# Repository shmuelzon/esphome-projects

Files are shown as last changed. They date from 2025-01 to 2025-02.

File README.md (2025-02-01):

# ESPHome Projects

This repository holds some of the ESPHome-based projects I've developed.

The directory structure is as follows:
* In the root you will find all of the ESPHome YAML files for each projects
* 3D-printable cases, if applicable, can be found in the [3d](./3d) directory
  * This were written for OpenSCAD but generated STL files are included
  * Note that each STL file may include multiple objects, e.g., the top and bottom part of a case. Make sure to separate those in your slicer before slicing and printing
* The [doc](./doc) directory holds the build information for each project

## List of Projects

| Image | Description | Documentation |
| ----- |:----:|:----:|
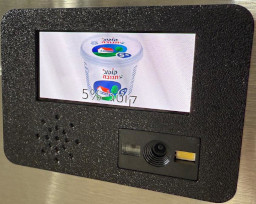
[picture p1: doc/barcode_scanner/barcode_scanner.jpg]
| [](./doc/barcode_scanner#readme) | Barcode Scanner that automatically add items to groceries list while displaying an image of the product and calling out it's name | [Documentation](./doc/barcode_scanner#readme) |
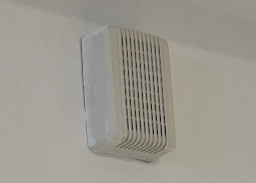
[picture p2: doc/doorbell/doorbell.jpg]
| [](./doc/doorbell#readme) | Doorbell with customizable audio tracks and media player for HA text-to-speech | [Documentation](./doc/doorbell#readme) |

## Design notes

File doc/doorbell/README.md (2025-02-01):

# Doorbell

This project is meant as a drop-in replacement to my existing doorbell buzzer. It uses the same infrastructure and illuminated push-button for activating it.

## Build

### Bill of Materials

| Name | Image | Quantity | Comments |
| ---- | ----- | --- | --- |
| SeeedStudio XIAO ESP32S3 |  XIAO ESP32S3 | 1 | |
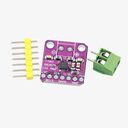
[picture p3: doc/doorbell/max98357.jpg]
MAX98357
| MAX98357 I2S Audio Amplifier Module |  | 1 | |
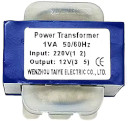
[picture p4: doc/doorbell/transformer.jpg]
Transformer
| Transformer |  | 1 | 220v -> 12v |
| AC-DC Power supply | Power supply | 1 | 5v |
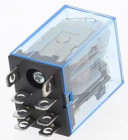
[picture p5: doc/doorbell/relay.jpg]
AC Relay
| AC Relay |  | 1 | 12v AC |
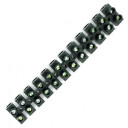
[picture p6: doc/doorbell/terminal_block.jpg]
| Terminal block |  | 4 | Split to two pairs |
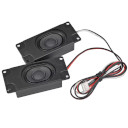
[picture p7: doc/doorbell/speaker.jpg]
Speaker
| Speaker |  | 1 | 4 Ohm, 3W |
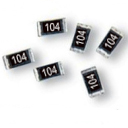
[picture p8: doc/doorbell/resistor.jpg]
100k resistor
| 100k resistor |  | 1 | Optional, set's the Amplifier to 15dB gain instead of 9dB |
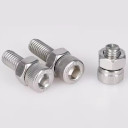
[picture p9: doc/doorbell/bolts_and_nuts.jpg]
M3x10 bolts and nuts
| M3x10 bolts and nuts |  | 4 | |

## Connections

MAX98357:
* LRC -> GPIO 44
* BCLK -> GPIO 7
* DIN -> GPIO 8
* Gain -> 100K resistor, the other end of the resistor to GND
* GND -> GND
* VIN -> 3.3v

Speaker:
* Red -> MAX98357 +
* Black -> MAX98357 -

Transformer:
* Primary (side with 2 pins) -> Live (AC) terminal block
* Secondary side -> One pin to the relay input and another to the button terminal block

Relay:
* Coil -> One side to the transformer, the other to the button terminal block
* Top contact (closer to the coil) -> GPIO 1
* Middle contact -> GND

AC-DC power supply:
* Mains -> Live (AC) terminal block
* 5v -> Xiao 5v
* GND -> GND

Live terminal block:
* AC Phase and neutral

Button terminal block:
* 2 leads to the illuminated doorbell push button

## Images
| Front | Back |
| ----- | ---- |
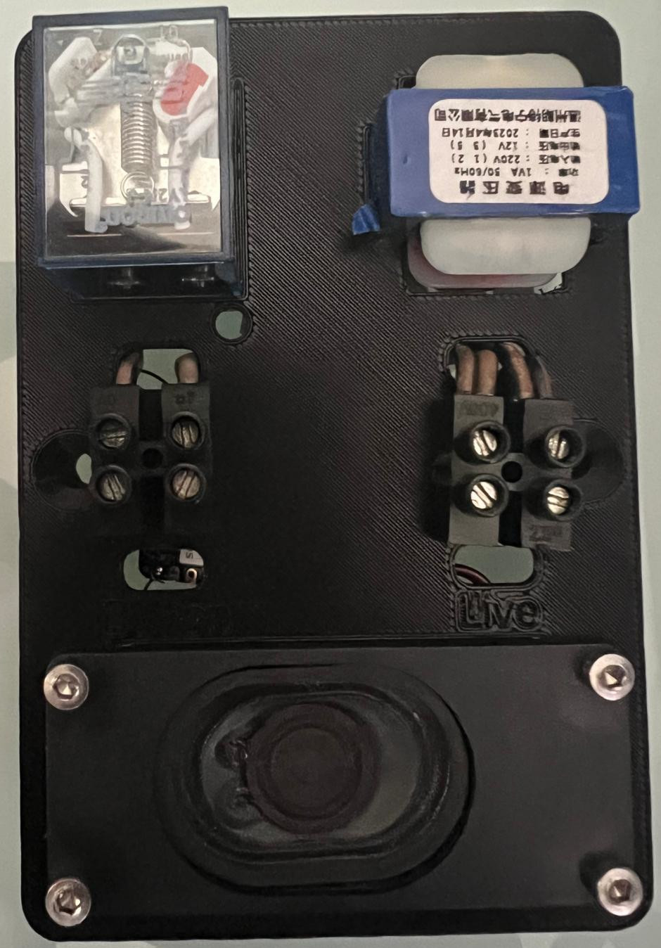
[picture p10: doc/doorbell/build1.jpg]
Build 1
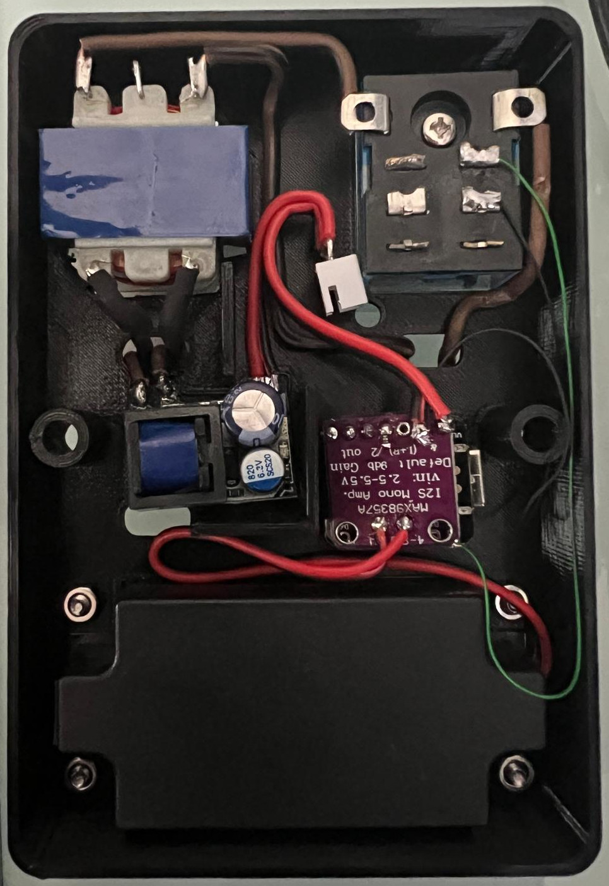
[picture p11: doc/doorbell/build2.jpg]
Build 2
|  |  |

## Misc

### Media Player

The doorbell also functions as a Home Assistant media player meaning you can play any supported audio on it, as well as use text-to-speech actions on it for various notifications.

### MQTT

While Home Assistant already enumerates the button for automations and such, I also opted to enable MQTT so that other services, e.g., Scrypted, can get events when the doorbell is pressed. The topic for the button is `doorbell/binary_sensor/button/state` with a payload of `ON` or `OFF`.

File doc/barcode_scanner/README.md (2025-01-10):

# Barcode Scanner

## Build

### Bill of Materials

| Name | Image | Quantity | Comments |
| ---- | ----- | --- | --- |
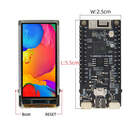
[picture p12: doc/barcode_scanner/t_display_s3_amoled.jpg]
S3 AMOLED
| LILYGO T-Display S3 AMOLED |  | 1 | v2.0, without touch screen nor soldered pins |
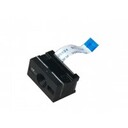
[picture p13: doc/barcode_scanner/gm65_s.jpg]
GM65-S
| GM65-S Barcode Scanner |  | 1 | |
| MAX98357 I2S Audio Amplifier Module | MAX98357 | 1 | |
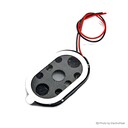
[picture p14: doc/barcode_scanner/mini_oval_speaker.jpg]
Speaker
| Mini Oval Speaker|  | 1 | 24x15mm 8ohm 1w |
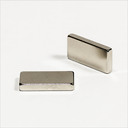
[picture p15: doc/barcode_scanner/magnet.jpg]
Magnet
| Magnet |  | 2 | Only needed for mounting on, for example, a refrigerator |
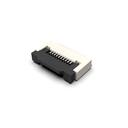
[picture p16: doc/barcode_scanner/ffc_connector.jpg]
FFC Connector
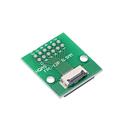
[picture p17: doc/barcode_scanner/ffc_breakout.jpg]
FFC Breakout
| FFC connector / breakout board |  /  | 1 | 12p 0.5mm pitch |
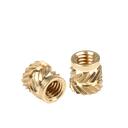
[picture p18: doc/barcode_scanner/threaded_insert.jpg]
Threaded inserts
| Threaded inserts |  | 3 | M3x5 |
| Countersunk screws | Countersunk screws | 3 | M3x8 |
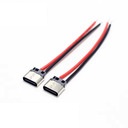
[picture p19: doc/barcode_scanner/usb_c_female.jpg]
USB-C Female
| USB-C Female |  | 1 | Should be as short as possible. I resoldered the leads to point the other way so it would sit flush in the case |
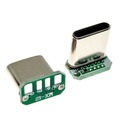
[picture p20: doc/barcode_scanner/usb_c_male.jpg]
USB-C Male
| USB-C Male |  | 1 | Should be as short as possible |
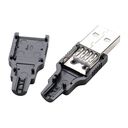
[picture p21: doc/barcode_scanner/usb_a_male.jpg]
USB-A Male
| USB-A Male |  | 1 | Depending on power source |

## Connections

Barcode Scanner:
* Pin 2 (VCC) -> 3.3v
* Pin 3 (GND) -> GND
* Pin 4 (RX) -> GPIO 43
* Pin 5 (TX) -> GPIO 44

> [!TIP]
> You might also need, even if temporarily, to connect pin 12 of the scanner to set it up. See the [Barcode Scanner Setup](#barcode-scanner-setup) section for more information

MAX98357:
* LRC -> GPIO 42
* BCLK -> GPIO 41
* DIN -> GPIO 40
* GND -> GND
* VIN -> 3.3v

USB-C Female:
* Red -> 5V
* Black -> GND

## Images
| Front | Back |
| ----- | ---- |
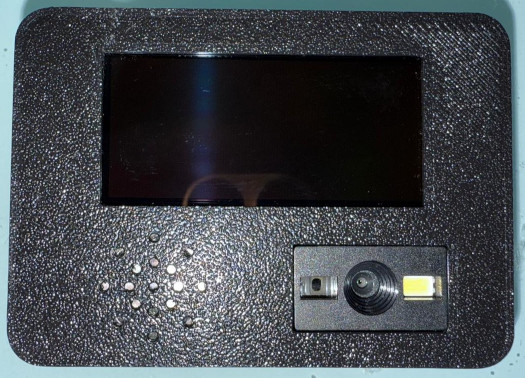
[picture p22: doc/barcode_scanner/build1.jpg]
Build 1
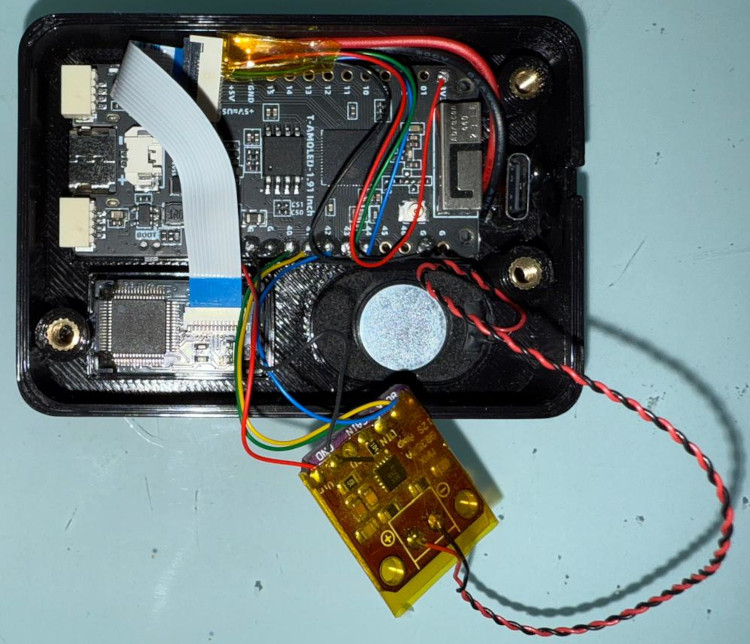
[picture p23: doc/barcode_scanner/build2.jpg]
Build 2
|  |  |

## Home Assistant

* Place font file (e.g., `DejaVuSans.ttf`) in `/config`
* Place the [barcode_unknown.png](./barcode_unknown.png) image in `/config/www`

### Configuration

We need to make use of the following Home Assistant integrations for retrieving the product information and for generating the display image with the product name overlaid:

> [!NOTE]
> Change the font name of the shell command to match the chosen font file

```yaml
rest_command:
  product_from_barcode:
    url: "https://world.openfoodfacts.org/api/v2/product/{{ barcode }}?fields=brands,product_name,product_name_he,code,selected_images"
    timeout: 30

shell_command:
  barcode_image: ffmpeg -i {{ image_url }} -vf "scale=536:240:force_original_aspect_ratio=decrease,pad=536:240:x=(536-iw)/2:y=(240-ih)/2:color=white,drawtext=text='{{ caption | replace("'", "'\\\\\\\\\\\''") }}':fontfile=/config/DejaVuSans.ttf:x=(w-text_w)/2:y=(h-text_h):fontsize=48:fontcolor=black:borderw=1:bordercolor=white:expansion=none" -frames:v 1 -update 1 -y {{ destination }}
```

### Automation

The following automation will trigger when a barcode is detected and attempt to retrieve its information. If it succeeds, it'll create an image to display and use TTS to send the product name to the scanner. Finally, it'll add the product to your to-do list. If the product isn't detect and "unknown" image will be displayed and a notification sent.

> [!NOTE]
> The below automation prioritizes the Hebrew product names and images, be sure to change that, if needed.
>
> Change the `<HA IP>` place holder with the IP address / host name of your Home Assistant Instance.
>
> Change the to-do list and notify actions to match your setup.

```yaml
alias: Add item to shopping list
description: ""
triggers:
  - trigger: state
    entity_id:
      - sensor.barcode_scanner_barcode
conditions:
  - condition: not
    conditions:
      - condition: state
        entity_id: sensor.barcode_scanner_barcode
        state: unknown
      - condition: state
        entity_id: sensor.barcode_scanner_barcode
        state: unavailable
actions:
  - variables:
      barcode: |
        {{ states('sensor.barcode_scanner_barcode') }}
  - action: rest_command.product_from_barcode
    data:
      barcode: "{{ barcode }}"
    response_variable: barcode_response
  - if:
      - condition: template
        value_template: >-
          {{ barcode_response['status'] == 200 and
          barcode_response['content']['product'].get('product_name','') != ''
          and barcode_response['content']['product'].get('selected_images') !=
          None }}
    then:
      - variables:
          product_name: >
            {{ barcode_response['content']['product']['product_name_he'] if
            barcode_response['content']['product'].get('product_name_he', '') !=
            '' else barcode_response['content']['product']['product_name'] }}
          product_brand: >
            {{ barcode_response['content']['product'].get('brands',
            '').split(',')[0] }}
          product_image: >
            {{
            barcode_response['content']['product']['selected_images']['front']['display']['he']
            if
            barcode_response['content']['product']['selected_images']['front']['display'].get('he')
            != None else
            barcode_response['content']['product']['selected_images']['front']['display']['en']
            }}
          product_full_name: |
            {{ product_name }} {{ product_brand }}
      - action: shell_command.barcode_image
        data:
          image_url: "{{ product_image }}"
          caption: "{{ product_name }}"
          destination: /config/www/barcode_product.png
      - action: text.set_value
        metadata: {}
        data:
          value: >-
            http://<HA IP>:8123/local/barcode_product.png?random={{
            as_timestamp(now()) | int }}
        target:
          entity_id: text.barcode_scanner_product_image_url
        enabled: true
      - action: tts.speak
        metadata: {}
        data:
          cache: true
          media_player_entity_id: media_player.barcode_scanner_media_player
          message: "{{ product_full_name }}"
          options:
            voice: he-IL-HilaNeural
        target:
          entity_id: tts.azure_ai_speech
      - if:
          - condition: template
            value_template: >-
              {{ product_full_name not in state_attr('todo.groceries_list',
              'all_todos') | map(attribute='subject') | list }}
        then:
          - action: todo.add_item
            metadata: {}
            data:
              item: "{{ product_full_name }}"
            target:
              entity_id: todo.groceries_list
          - action: notify.someone
            data:
              message: "{{ product_full_name }} was added to the groceries list"
    else:
      - action: text.set_value
        metadata: {}
        data:
          value: >-
            http://<HA IP>:8123/local/barcode_unknown.png?random={{
            as_timestamp(now()) | int }}
        target:
          entity_id: text.barcode_scanner_product_image_url
        enabled: true
      - action: notify.someone
        data:
          message: "Unknown barcode was scanned: {{ barcode }}"
mode: single
```

## Misc

### Barcode Scanner Setup

To simplify the project, I've opted to set the scanner to work in continuous mode without waiting between attempts. Look for the GM65-S manual online and you'll find QR codes you can scan to configure the device it self. Note that you'll need to trigger the scanner at least once to set it to continuous mode.  This is done by pulling pin 12 to low.

### Beep Sound

The common cash register sound is a 860 Hz square wave. I created a similar one (sine wave) with FFmpeg:

```shell
ffmpeg -f lavfi -i "sine=frequency=860:sample_rate=16000:duration=0.2" -ac 1 -af "volume=20dB" -sample_fmt s16 -c:a flac -y sounds/beep_of_a_cash_register.flac
```

### Open Food Facts Proxy

Sometimes Open Food Fact's website is a bit slow to respond. If you find that's the case often, you might want to consider adding a caching reverse-proxy. The following nginx configuration seems to work:

```nginx
http {
    proxy_cache_path  /cache levels=1:2 keys_zone=my-cache:8m max_size=1000m inactive=1y;
    proxy_temp_path /cache/tmp;

    server {
        listen 8081;
        listen [::]:8081;

        location / {
            proxy_pass https://world.openfoodfacts.org;
            proxy_cache my-cache;
            proxy_cache_valid 1y;
            proxy_cache_bypass $http_invalidate_cache;
        }
    }
}
```

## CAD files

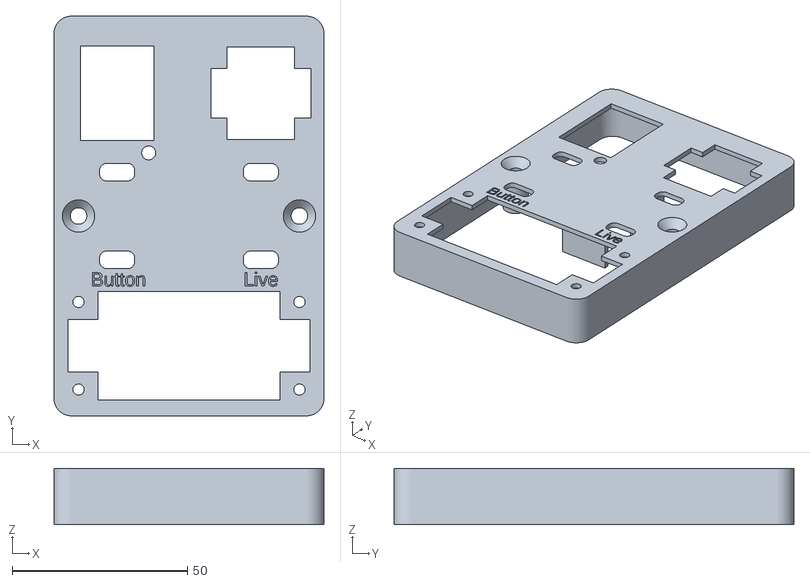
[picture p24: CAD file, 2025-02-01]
3d/doorbell.stl
77.0 x 114.0 x 16.0

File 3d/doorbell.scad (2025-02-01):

$fn=36;

/* General */
epsilon = 0.01;
mechanical_clearence = 0.1; /* Set according to printer's accuracy */

/* Case */
case_wall_thickness = 1.6;
case_depth = 16;
case_width = 77;
case_height = 114;
case_edge_radius = 5;

module round_cube(size=[0, 0, 0], r=2)
{
  minkowski()
  {
    cube([size[0] - (2 * r), size[1] - (2 * r), size[2] - 0.01]);
    translate([r, r, 0]) cylinder(r=r, h=0.01);
  }
}

module centered_cube(size=[0, 0, 0])
{
  translate([-size[0] / 2, -size[1] / 2, 0]) cube(size);
}

module countersunk_screw(length)
{
  color("gray")
  {
    cylinder(h=3, r1=4.5 + mechanical_clearence, r2=2.25 + mechanical_clearence);
    translate([0, 0, 3]) cylinder(h=length, r=2.25 + mechanical_clearence);
  }
}

module m3_hex_screw(length)
{
  color("gray")
  {
    cylinder(h=2, r=2.2 + mechanical_clearence);
    translate([0, 0, 2]) cylinder(h=length, r=1.5 + mechanical_clearence);
  }
}

module case()
{
  difference()
  {
    round_cube([case_width, case_height, case_depth], r=case_edge_radius);
    translate([case_wall_thickness, case_wall_thickness, -case_wall_thickness]) round_cube([case_width - (case_wall_thickness * 2), case_height - (case_wall_thickness * 2), case_depth], r=case_edge_radius);
    /* Button wiring */
    translate([13, 67, case_depth - case_wall_thickness - epsilon]) round_cube([10, 5, case_wall_thickness + (2 * epsilon)]);
    translate([13, 42, case_depth - case_wall_thickness - epsilon]) round_cube([10, 5, case_wall_thickness + (2 * epsilon)]);
    translate([10.5, 37, case_depth - 0.5]) linear_extrude(height=0.5) text("Button", size=4);
    /* Live wiring */
    translate([54, 67, case_depth - case_wall_thickness - epsilon]) round_cube([10, 5, case_wall_thickness + (2 * epsilon)]);
    translate([54, 42, case_depth - case_wall_thickness - epsilon]) round_cube([10, 5, case_wall_thickness + (2 * epsilon)]);
    translate([54, 37, case_depth - 0.5]) linear_extrude(height=0.5) text("Live", size=4);
    /* Antenna wire */
    translate([27, 75, case_depth - case_wall_thickness - epsilon]) cylinder(r = 2, h = case_wall_thickness + (2 * epsilon));
  }
  /* AC/DC separator */
  translate([47, 65, 0]) cube([case_wall_thickness, 15, case_depth]);
  translate([36, 44, 0]) cube([case_wall_thickness, 20, case_depth]);
  translate([37, 44, 0]) cube([16, case_wall_thickness, case_depth]);
  /* Screw mounts */
  translate([7, case_height / 2, 0]) cylinder(r = 4, h=case_depth);
  translate([case_width - 7, case_height / 2, 0]) cylinder(r = 4, h=case_depth);
}

module hardware()
{
  /* Wall-mount screws */
  translate([7, case_height / 2, case_depth]) rotate([180, 0, 0]) countersunk_screw(length=case_depth);
  translate([case_width - 7, case_height / 2, case_depth]) rotate([180, 0, 0]) countersunk_screw(length=case_depth);
  /* Speaker mount screws */
  translate([7, 7.5, 20]) rotate([180, 0, 0]) m3_hex_screw(length=10);
  translate([70, 7.5, 20]) rotate([180, 0, 0]) m3_hex_screw(length=10);
  translate([7, 32.5, 20]) rotate([180, 0, 0]) m3_hex_screw(length=10);
  translate([70, 32.5, 20]) rotate([180, 0, 0]) m3_hex_screw(length=10);
}

module transformer()
{
  color("gray")
  {
    centered_cube([28.5, 14, 25.5]);
    centered_cube([19.2, 26.5, 23]);
  }
}

module relay()
{
  color("cyan")
  {
    centered_cube([21, 27, 41]);
  }
}

module speaker()
{
  color("black")
  translate([0, 0, 16 / 2])
  {
    translate([0, 0, 7])
    difference()
    {
      cube([69, 31, 2], center=true);
      translate([-31.5, -12.5, -1]) cylinder(h=2, r=1.5);
      translate([31.5, -12.5, -1]) cylinder(h=2, r=1.5);
      translate([-31.5, 12.5, -1]) cylinder(h=2, r=1.5);
      translate([31.5, 12.5, -1]) cylinder(h=2, r=1.5);
    }
    translate([0, 0, -1]) cube([52, 31, 14], center=true);
    translate([0, 0, -1]) cube([69, 15, 14], center=true);
  }
}

module amp()
{
  color("purple")
  {
    centered_cube([18.8, 17.4, 1.6]);
  }
}

module xiao()
{
  color("black")
  {
    centered_cube([21, 18, 1.6]);
  }
}

module antenna()
{
  color("black")
  {
    centered_cube([20, 40, 1]);
  }
}

module powerConverter()
{
  color("blue")
  {
    centered_cube([23.6, 15.3, 15.2]);
    /* DC Connector */
    translate([23.6 / 2 - 6 / 2, -15.3 / 2 - 3 / 2, 15.2 - 1.2])centered_cube([6, 3, 1.2]);
    /* AC Connector */
    translate([-23.6 / 2 + 7.5 / 2, -15.3 / 2 - 3 / 2, 15.2 - 1.2])centered_cube([7.5, 3, 1.2]);
  }
}

module electronics()
{
  translate([59, 92, 0]) transformer();
  translate([18, 92, 0]) relay();
  translate([23, 57, 0]) amp();
  translate([23, 57, 10]) xiao();
  translate([39, 59, case_depth]) antenna();
  translate([51, 55.5, 0]) rotate([0, 0, 180]) powerConverter();
  translate([(case_width / 2), 20, 2]) speaker();
}

difference()
{
  union()
  {
    case();
  }
  if (!$preview)
  {
    electronics();
    hardware();
  }
}

if ($preview)
{
  electronics();
  hardware();
}

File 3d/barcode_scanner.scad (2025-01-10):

$fn=36;
show_top = true;
show_bottom = true;

/* General */
epsilon = 0.01;
mechanical_clearance = 0.1; /* Set according to printer's accuracy */

/* Case */
case_wall_thickness = 1.6;
case_depth = 15;
case_width = 70;
case_height = 50;
case_edge_radius = 5;

screws_locations = [[-28.5, 17],[-28.5, -7],[29.5, -15]];


module m3_countersunk_screw(length)
{
  color("gray")
  {
    cylinder(h=2, r1=3 + mechanical_clearance, r2=1.5 + mechanical_clearance);
    translate([0, 0, 2]) cylinder(h=length, r=1.5 + mechanical_clearance);
  }
}

module m3_thread_insert(base_length=0)
{
  cylinder(r=3.5, h=base_length);
  translate([0, 0, base_length])
  difference()
  {
    cylinder(r=3.5, h=7.5);
    cylinder(r=1.8 + mechanical_clearance, h=7.5 + epsilon);
    translate([0, 0, 6.5]) cylinder(r1=1.8 + mechanical_clearance, r2=2.1 + mechanical_clearance, h=1 + epsilon);
  }
}

module round_cube(size=[0, 0, 0], r=2)
{
  translate([-size[0] / 2, -size[1] / 2, -size[2] / 2])
  minkowski()
  {
    cube([size[0] - (2 * r), size[1] - (2 * r), size[2] - 0.01]);
    translate([r, r, 0]) cylinder(r=r, h=0.01);
  }
}

module barcode_scanner()
{
  size = [21.4, 11.8, 14];
  distance_between_threads = 14.6;
  thread_diameter = 1.4;
  screw_keepout = 3;
  
  color("#303030") cube([for (i=[0:len(size)-1]) size[i] + mechanical_clearance], center=true);
  /* Screw keepout */
  #translate([-distance_between_threads / 2, size[1] / 2, 0]) rotate([270, 0, 0]) cylinder(r=thread_diameter / 2, h=screw_keepout);
  #translate([ distance_between_threads / 2, size[1] / 2, 0]) rotate([270, 0, 0]) cylinder(r=thread_diameter / 2, h=screw_keepout);
}

module usb_cable()
{
  color("green") translate([-0.3, -0.5, 0]) cube([6.5, 10, 2]);
  #translate([-20, -0.5 + (10/2) - (3.5/2), 0]) cube([20, 3.5, 2]);
  color("silver") translate([5.6-2.35, 0, 2]) cube([2.35, 9, 8.3]);

  /* keepout (for female connector */
  #translate([5.6-2.7, 0, 10.3]) cube([3, 9, 4]);
  #translate([5.6-2.7+3, 0, 10.3]) cube([2, 6, 4]);
}

module speaker()
{
  size = [24, 15, 3];
  keepout_radius = 0.75;
  number_of_keepout_circles = 3;
  number_of_keepout_branches = 8;
  keepout_max_radius = min(size[0], size[1]) / 2 - keepout_radius;

  color("#303030") round_cube([for (i=[0:len(size)-1]) size[i] + mechanical_clearance], r=(size[1] + mechanical_clearance) /2 - epsilon);
  if (true)
  {
    for (radius=[0 : keepout_max_radius / (number_of_keepout_circles - 1) : keepout_max_radius])
    {
      for (degree=[0 : 360 / number_of_keepout_branches : 360])
        #translate([radius * cos(degree), radius * sin(degree), size[2] / 2]) cylinder(r=keepout_radius, h=5);
    }
  }
  else
  {
    for (radius=[0 : number_of_keepout_circles])
    {
      for (degree=[0 : 360 / number_of_keepout_branches : 360])
        #translate([size[0] * (radius  / number_of_keepout_circles) * cos(degree) / 2, size[1] * (radius / number_of_keepout_circles) * sin(degree) / 2, size[2] / 2]) cylinder(r=keepout_radius, h=5);
    }
  }
}

module amp()
{
  size=[18.8, 17.5, 1.6];
  color("purple") round_cube([for (i=[0:len(size)-1]) size[i] + mechanical_clearance], r=1);
}

module display()
{
  size = [54.2, 25.6, 9.8]; /*54.2*/

  color("#303030") cube([for (i=[0:len(size)-1]) size[i] + mechanical_clearance], center=true);
  #translate([-2.5, 0, size[2] / 2]) cube([45, 21.5, 10], center=true);
  
}

module case_top()
{
  difference()
  {
    round_cube([case_width, case_height, case_depth], r=case_edge_radius);
    translate([0,0,-case_wall_thickness - 2]) round_cube([case_width - (case_wall_thickness * 2), case_height - (case_wall_thickness * 2), case_depth], r=case_edge_radius);
  }

  /* Barcode scanner screw mount */
  translate([3, -21, -2]) cube([24, 14, 7]);

  /* Screw stand-offs */
  for (screw = screws_locations)
    translate([screw[0], screw[1], case_wall_thickness + 3]) rotate([180, 0, 0]) m3_thread_insert(3);
}

module case_bottom()
{
  translate([0, 0, -case_depth / 2 + case_wall_thickness / 2]) round_cube([case_width - (case_wall_thickness * 2) - (mechanical_clearance * 2), case_height - (case_wall_thickness * 2) - (mechanical_clearance * 2), case_wall_thickness], r=case_edge_radius);
}

module case()
{
  union()
  {
    if (show_top)
      case_top();
    if (show_bottom)
      case_bottom();
  }
}

module electronics()
{
  translate([2.5, 8, 1.5]) display();
  translate([-15, -14, 5]) speaker();
  translate([-15, -14, 0]) amp();
  translate([15, -14, 0.5]) barcode_scanner();
  translate([-33, 0, -7.5]) usb_cable();
}

module hardware()
{
  /* Screw inserts */
  for (screw = screws_locations)
    translate([screw[0], screw[1], -case_depth + 7.5]) m3_countersunk_screw(8);

  /* Magnets */
  magnet_locations=[[20,5], [-20,5]];
  for (magnet = magnet_locations)
    color("silver") translate([magnet[0], magnet[1], -case_depth / 2 + 1.85]) cube([9.5, 20, 2.7], center=true);
}

difference()
{
  union()
  {
    case();
  }
  if (!$preview)
  {
    electronics();
    hardware();
  }
}

if ($preview)
{
  electronics();
  hardware();
}

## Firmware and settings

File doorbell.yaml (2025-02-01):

esphome:
  name: doorbell
  friendly_name: Doorbell
  platformio_options:
    upload_speed: 921600

external_components:
  - source: github://pr#7672
    components:
      - audio
      - speaker
      - i2s_audio

esp32:
  board: esp32-s3-devkitc-1
  variant: esp32s3
  framework:
    type: esp-idf

psram:
  mode: octal

# Enable logging
logger:

# Enable Home Assistant API
api:
  password: ""

http_request:
  timeout: 30s
  verify_ssl: false

ota:
  - platform: esphome
    password: !secret ota_password

wifi:
  ssid: !secret wifi_ssid
  password: !secret wifi_password

  # Enable fallback hotspot (captive portal) in case wifi connection fails
  ap:
    ssid: "Doorbell Fallback Hotspot"
    password: !secret hotspot_password

captive_portal:

mqtt:
  broker: !secret mqtt_broker
  discovery: false

i2s_audio:
  i2s_lrclk_pin: 44
  i2s_bclk_pin: 7

speaker:
  - platform: i2s_audio
    id: speaker_id
    dac_type: external
    i2s_dout_pin: 8
    channel: mono
    bits_per_sample: 16bit
    sample_rate: 48000

media_player:
  - platform: speaker
    id: speaker_media_player
    name: "Media Player"
    speaker: speaker_id
    sample_rate: 48000
    files:
      - id: ding_dong
        file: sounds/ding_dong.flac
      - id: anybody_home
        file: sounds/anybody_home.flac

select:
  - platform: template
    id: audio_file
    name: "Audio file"
    optimistic: true
    options:
      - "Ding Dong"
      - "Anybody Home?"
    restore_value: true
    initial_option: "Ding Dong"

button:
  - platform: template
    name: "Ring bell"
    on_press:
      then:
        - script.execute: play_audio

binary_sensor:
  - platform: gpio
    name: "Button"
    pin:
      number: 1
      mode:
        input: true
        pullup: true
      inverted: true
    filters:
      - delayed_on: 10ms
    on_press:
      then:
        - script.execute: play_audio

script:
  - id: play_audio
    then:
      - lambda: |-
          id(speaker_media_player).play_file(id(audio_file).state == "Ding Dong" ? id(ding_dong) : id(anybody_home), false);

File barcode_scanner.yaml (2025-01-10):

esphome:
  name: barcode-scanner
  friendly_name: Barcode Scanner
  platformio_options:
    upload_speed: 921600

external_components:
  - source: github://pr#7672
    components:
      - audio
      - speaker
      - i2s_audio

esp32:
  board: esp32-s3-devkitc-1
  variant: esp32s3
  framework:
    type: esp-idf

psram:
  mode: octal

# Enable logging
logger:
  level: DEBUG

# Enable Home Assistant API
api:
  password: ""

http_request:
  timeout: 30s
  verify_ssl: false

ota:
  - platform: esphome
    password: !secret ota_password

wifi:
  ssid: !secret wifi_ssid
  password: !secret wifi_password

  # Enable fallback hotspot (captive portal) in case wifi connection fails
  ap:
    ssid: "Barcode-Scanner Fallback Hotspot"
    password: !secret hotspot_password

captive_portal:

i2s_audio:
  i2s_lrclk_pin: 42
  i2s_bclk_pin: 41

spi:
  id: quad_spi
  type: quad
  clk_pin: 47
  data_pins:
    - 18
    - 7
    - 48
    - 5

uart:
  id: scanner_uart
  tx_pin: 43
  rx_pin: 44
  baud_rate: 9600
  debug:
    direction: BOTH
    dummy_receiver: true
    after:
      delimiter: "\r"
    sequence:
      - lambda: |-
          UARTDebug::log_string(direction, bytes);
          std::string str(bytes.begin(), std::prev(bytes.end()));
          id(internal_barcode).publish_state(str.c_str());

display:
  - platform: qspi_dbi
    model: RM67162
    id: display_id
    dimensions:
      height: 240
      width: 536
    transform:
      mirror_x: true
      swap_xy: true
    color_order: rgb
    brightness: 255
    cs_pin: 6
    reset_pin: 17
    enable_pin: 38
    update_interval: never
    auto_clear_enabled: false

speaker:
  - platform: i2s_audio
    id: speaker_id
    dac_type: external
    i2s_dout_pin: 40
    channel: mono
    bits_per_sample: 16bit
    sample_rate: 16000

media_player:
  - platform: speaker
    name: "Media Player"
    speaker: speaker_id
    sample_rate: 16000
    files:
      - id: beep_of_a_cash_register
        file: sounds/beep_of_a_cash_register.flac

lvgl:
  msgboxes:
    - id: error_message
      title: "Error"
      body:
        text: "Failed downloading image"
        text_color: white
  pages:
    - id: idle
      bg_color: black
    - id: loading
      bg_color: black
      widgets:
        - spinner:
            align: center
            spin_time: 2s
            arc_length: 60deg
    - id: product
      widgets:
        - image:
            id: display_product_image
            src: product_image

text_sensor:
  - platform: template
    id: internal_barcode
    on_value:
      then:
        - speaker_media_player.play_local_media_file: beep_of_a_cash_register
        - lvgl.page.show: loading
        - lambda: id(barcode).publish_state(x.c_str());
        - delay: 1s
        - lambda: id(barcode).publish_state("unknown");
        - delay: 60s
        - lvgl.page.show: idle
  - platform: template
    id: barcode
    name: "Barcode"

text:
  - platform: template
    name: "Product Image URL"
    icon: mdi:image
    optimistic: true
    mode: text
    on_value:
      - online_image.set_url:
          id: product_image
          url: !lambda return x.c_str();

online_image:
  - url: "http://placeholder.png"
    id: product_image
    format: png
    type: RGB565
    on_download_finished:
      then:
        - lvgl.image.update:
            id: display_product_image
            src: product_image
        - lvgl.page.show: product
        - delay: 5s
        - lvgl.page.show: idle
    on_error:
        - lvgl.widget.show: error_message
        - delay: 5s
        - lvgl.widget.hide: error_message
        - lvgl.page.show: idle
